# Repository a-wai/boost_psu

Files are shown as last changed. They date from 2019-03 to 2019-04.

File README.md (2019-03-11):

# Boost PSU for tube preamplifiers

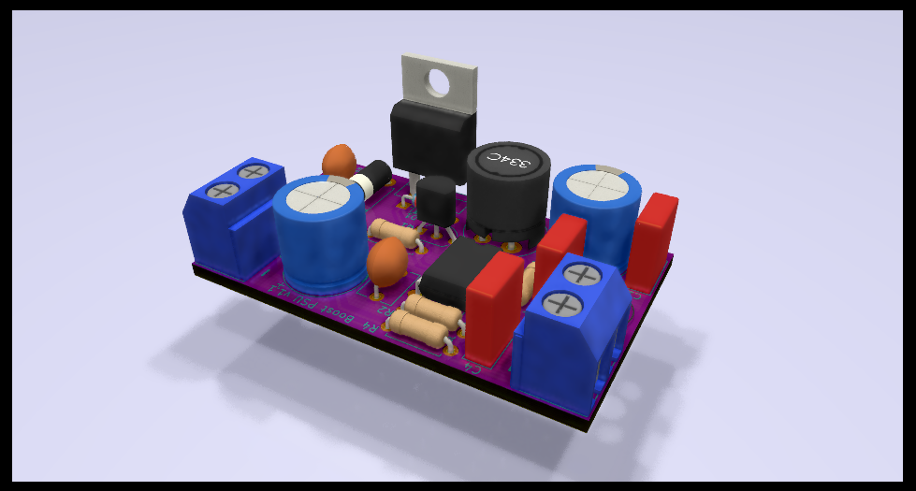
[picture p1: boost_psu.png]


This power supply is based on a MC34063A DC/DC converter. It can output up to 300V from a 12V DC input.

### Copyright

Copyright 2019, LEMON Amps.
Copyright 2019, Arnaud Ferraris.

This documentation describes Open Hardware and is licensed under the
CERN OHL v.1.2.

You may redistribute and modify this documentation under the terms of the
[CERN OHL v.1.2](http://ohwr.org/cernohl). This documentation is distributed
WITHOUT ANY EXPRESS OR IMPLIED WARRANTY, INCLUDING OF MERCHANTABILITY,
SATISFACTORY QUALITY AND FITNESS FOR A PARTICULAR PURPOSE.

Please see the CERN OHL v.1.2 for applicable conditions.

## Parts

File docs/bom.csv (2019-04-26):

Component | Description | References | Value | Quantity Per PCB | MFR | MPN | SPR | SPN
1 | Unpolarized capacitor | C2 C4 C7 | 100n | 3 | WIMA | MKS2D031001A00KI00 | RS | 108-2700
2 | Unpolarized capacitor | C5 | 10n/400V | 1 | KEMET | C322C103KBR5TA | RS | 906-0654
3 | Polarized capacitor | C6 | 4.7µ/350V | 1 | Nichicon | UBT2V4R7MPD8 | RS | 762-1890
4 | Unpolarized capacitor | C3 | 470p | 1 | KEMET | C322C471J2G5TA | RS | 538-1534
5 | Polarized capacitor | C1 | 470µ | 1 | Nichicon | UVR1V471MPD | RS | 862-3370
6 | Diode | D1 | 1N4148 | 1 | ON Semiconductor | 1N4148TR | RS | 671-5477
7 | Diode | D2 | BYV26 | 1 | Vishay | BYV26E-TAP | RS | 708-7776
8 | Generic connector, single row, 01x02, script generated (kicad-library-utils/schlib/autogen/connector/) | J1 | +12V | 1 | Wurth Elektronik | 691102710002 | RS | 826-7226
9 | Generic connector, single row, 01x02, script generated (kicad-library-utils/schlib/autogen/connector/) | J2 | HT | 1 | Wurth Elektronik | 691102710002 | RS | 826-7226
10 | Inductor | L1 | 100µH/1.5A | 1 | Murata Power Solutions | 12RS104C | RS | 715-7374
11 | 10A Id, 400V Vds, N-Channel Power MOSFET, 500mOhm Rds, TO-220AB | Q2 | IRF740 | 1 | Vishay | IRF740LCPBF | RS | 536-5992
12 | PNP transistor, emitter/base/collector | Q1 | MPS751 | 1 | ON Semiconductor | MPS751G | RS | 774-3583
13 | Resistor | R1 | 0.22R | 1 | TE Connectivity | LR1LJR22 | RS | 135-500
14 | Resistor | R2 | 1.8k | 1 | TE Connectivity | LR1F1K8 | RS | 148-562
15 | Resistor | R3 | 1k | 1 | TE Connectivity | LR1F1K0 | RS | 125-1159
16 | Resistor | R4 | 430k | 1 | TE Connectivity | YR1B432KCC | RS | 754-5759
17 | 1.5A, step-up/down/inverting switching regulator, 3-40V Vin, 100kHz, DIP-8 | U1 | MC34063AP | 1 | ON Semiconductor | MC34063AP1G | RS | 516-5095

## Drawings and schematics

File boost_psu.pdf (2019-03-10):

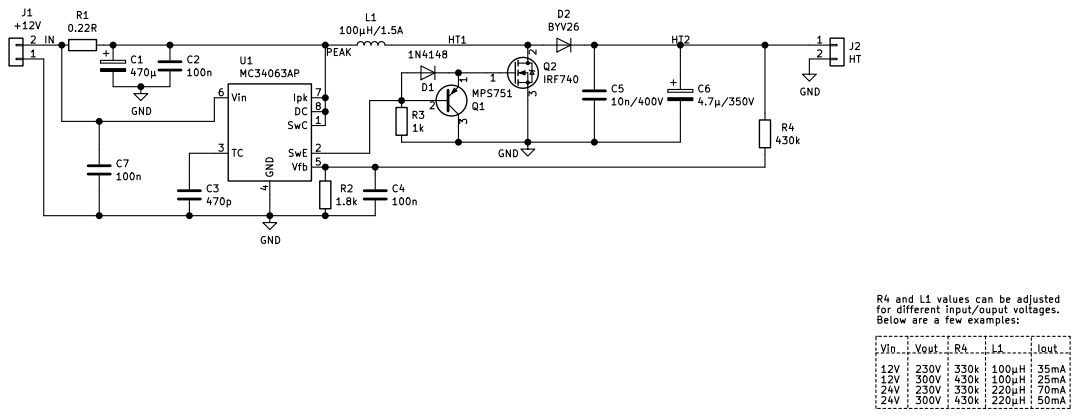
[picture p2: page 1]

50mA R4 and L1 values can be adjusted
for different input/ouput voltages.
Below are a few examples:

Licensed under CERN OHL v.1.2 Tube preamplifier power supply

File: boost_psu.sch Sheet: / Arnaud Ferraris (A-wai Amplification) & LEMON Amps

Id: 1/1 Title: Boost PSU

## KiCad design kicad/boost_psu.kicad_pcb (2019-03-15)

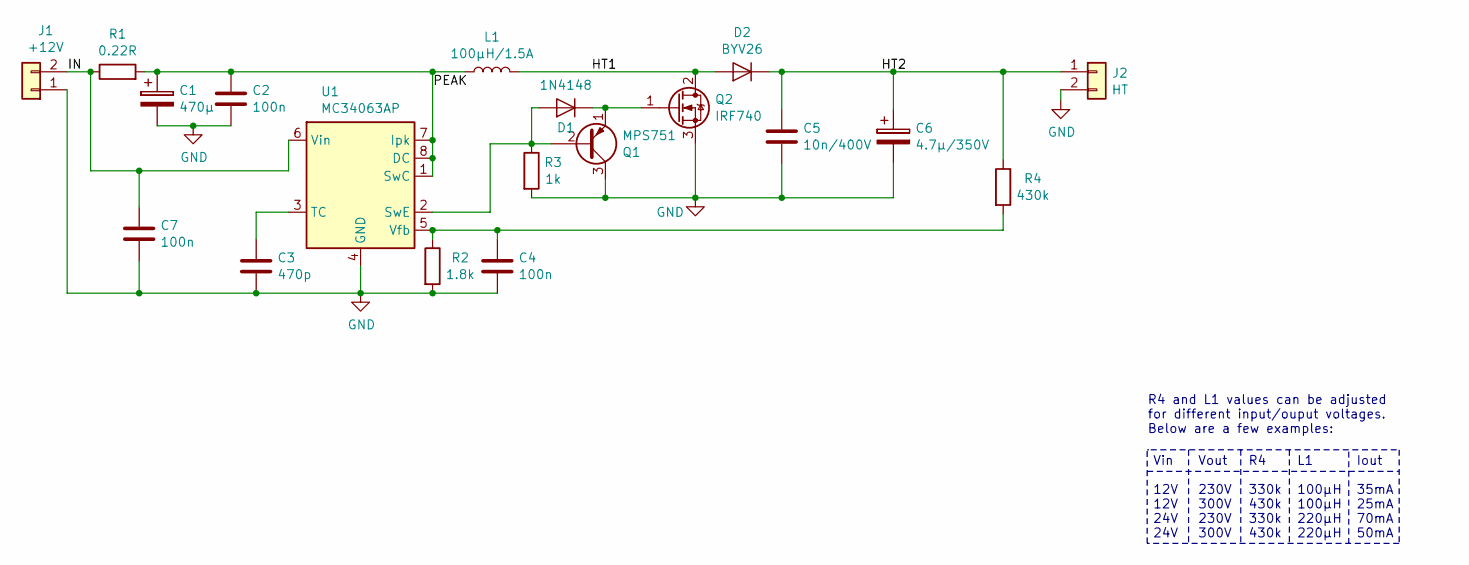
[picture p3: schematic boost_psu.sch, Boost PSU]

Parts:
C1: 470µ; CP_Radial_D10.0mm_P5.00mm; MPN UVR1V471MPD
C2, C4, C7: 100n; C_Rect_L7.2mm_W3.0mm_P5.00mm_FKS2_FKP2_MKS2_MKP2; MPN MKS2D031001A00KI00
C3: 470p; C_Disc_D6.0mm_W4.4mm_P5.00mm; MPN C322C471J2G5TA
C5: 10n/400V; C_Disc_D6.0mm_W4.4mm_P5.00mm; MPN C322C103KBR5TA
C6: 4.7µ/350V; CP_Radial_D10.0mm_P5.00mm; MPN UBT2V4R7MPD8
D1: 1N4148; D_DO-35_SOD27_P7.62mm_Horizontal; MPN 1N4148TR
D2: BYV26; D_DO-15_P10.16mm_Horizontal; MPN BYV26E-TAP
J1: +12V; TerminalBlock_bornier-2_P5.08mm; MPN 691102710002
J2: HT; TerminalBlock_bornier-2_P5.08mm; MPN 691102710002
L1: 100µH/1.5A; L_Radial_D10.5mm_P5.00mm_MuRATA_1200RS; MPN 12RS104C
Q1: MPS751; TO-92_Inline_Wide; MPN MPS751G
Q2: IRF740; TO-220-3_Vertical; MPN IRF740LCPBF
R1: 0.22R; R_Axial_DIN0207_L6.3mm_D2.5mm_P7.62mm_Horizontal; MPN LR1F220R
R2: 1.8k; R_Axial_DIN0207_L6.3mm_D2.5mm_P7.62mm_Horizontal; MPN LR1F1K8
R3: 1k; R_Axial_DIN0207_L6.3mm_D2.5mm_P7.62mm_Horizontal; MPN LR1F1K0
R4: 430k; R_Axial_DIN0207_L6.3mm_D2.5mm_P7.62mm_Horizontal; MPN YR1B432KCC
U1: MC34063AP; DIP-8_W7.62mm_LongPads; MPN MC34063AP1G

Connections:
/HT1: D2.2 (A), L1.2, Q2.2 (D)
/HT2: C5.1, C6.1, D2.1 (K), J2.1, R4.1
/IN: C7.1, J1.2, R1.1, U1.6 (Vin)
/PEAK: C1.1, C2.1, L1.1, R1.2, U1.1 (SwC), U1.7 (Ipk), U1.8 (DC)
GND: C1.2, C2.2, C3.2, C4.2, C5.2, C6.2, C7.2, J1.1, J2.2, Q1.3 (C), Q2.3 (S), R2.2, R3.2, U1.4 (GND)
unnamed: C3.1, U1.3 (TC)
unnamed: C4.1, R2.1, R4.2, U1.5 (Vfb)
unnamed: D1.1 (K), Q1.1 (E), Q2.1 (G)
unnamed: D1.2 (A), Q1.2 (B), R3.1, U1.2 (SwE)

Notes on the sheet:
Vin 12V 12V 24V 24V
Vout 230V 300V 230V 300V
R4 330k 430k 330k 430k
L1 100µH 100µH 220µH 220µH
Iout 35mA 25mA 70mA 50mA
R4 and L1 values can be adjusted for different input/ouput voltages. Below are a few examples:

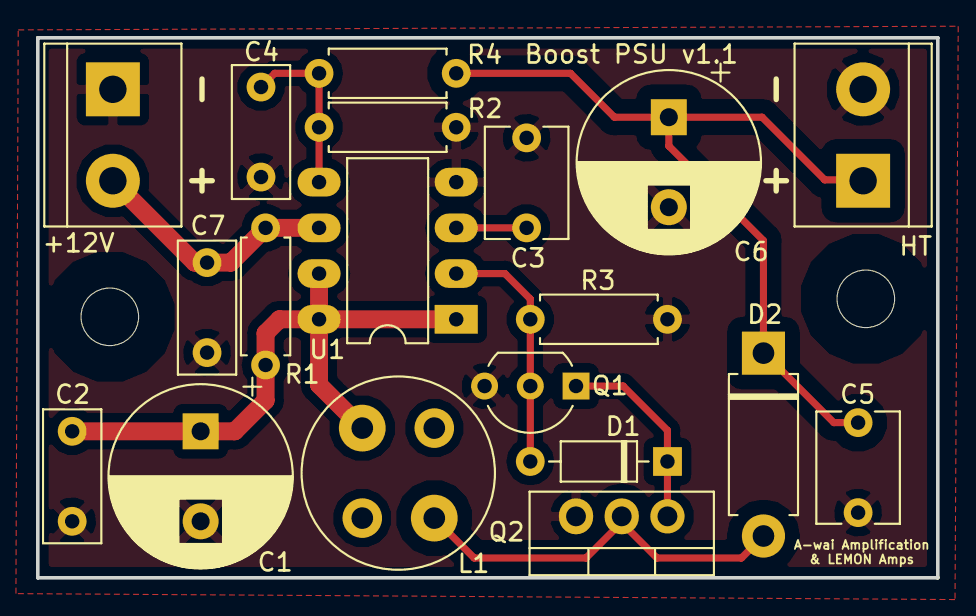
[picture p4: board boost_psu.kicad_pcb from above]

Board: 2 copper layers, 50.0 x 30.0 mm, 19 parts (0 on the bottom side), 9 nets.

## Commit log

2019-03-07 Add project information
    [boost_psu.kicad_pcb, boost_psu.sch]
2019-03-07 Add calculation spreadsheet
    [MC34063 calc.ods]
2019-03-07 Improve calculation spreadsheet
    [MC34063 calc.ods]
2019-03-09 Improve schematic & PCB routing
    - put filtering capacitors on the switch collector rather than Vin
    - add a 100n filtering capacitor on Vin
    - switch to a 30x50mm board for a better layout
    - add LEMON Amps as co-author
    [boost_psu.kicad_pcb, boost_psu.sch]
2019-03-09 Add emphasis in spreadsheet when exceeding max current
    [MC34063 calc.ods]
2019-03-09 Change IRF740 orientation
    As the MPSA55 is pretty close, it is better for the IRF740 tab to face
    outwards, in order not to dissipate heat towards the transistor.
    [boost_psu.kicad_pcb]
2019-03-10 Change a few footprints and rework schematics
    [boost_psu.kicad_pcb, boost_psu.sch]
2019-03-10 Rename PDF schematics file
2019-03-10 Update schematics PDF
2019-03-10 Fix transistor polarity
    [boost_psu.kicad_pcb, boost_psu.sch]
2019-03-11 Add BOM
    [bom.csv, boost_psu.sch]
2019-03-11 Move BOM files for serving through GH pages
    [bom.csv]
2019-03-11 Add PCB rendering image
2019-03-15 Fix inductor footprint & improve layout
    [boost_psu.kicad_pcb]
2019-03-15 Fix some markings orientations on silkscreen
    [boost_psu.kicad_pcb]
2019-03-30 Fix supplier refs in BOM
    [bom.csv, boost_psu.sch]
2019-04-25 Update BOM logo
2019-04-26 Fix R1 Manufacturer & Supplier Part Nr.
    [bom.csv, boost_psu.sch]
